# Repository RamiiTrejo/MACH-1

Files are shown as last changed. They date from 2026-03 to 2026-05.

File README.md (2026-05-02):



# Mach-1
Proyecto de robot seguidor de línea de alta velocidad, orientado a competencias de Line Follower Racing (LNR). Está diseñado para la categoría profesional, incorporando soluciones avanzadas como un sistema de succión que mejora la adherencia y el rendimiento en pista.

# Objetivos
Desarrollar un vehículo autónomo capaz de detectar y seguir una trayectoria con alta precisión y velocidad, optimizando tanto el hardware como el software para lograr un desempeño competitivo.

# Componentes
- ATMEGA238P, AU
- TA6586
- MOTOR CORELESS 8520
- TURBINA CON MOTOR CORELESS 716
- REGLETA QTR8A
- BATERÍA 2 350mAh~450mAh

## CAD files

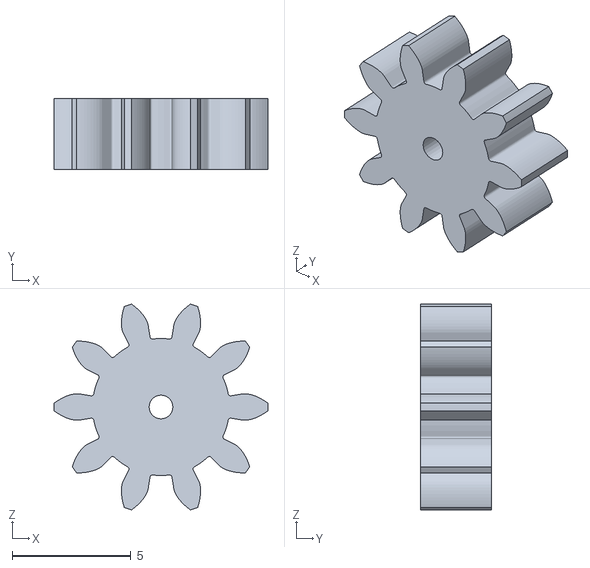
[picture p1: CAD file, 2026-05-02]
3D HARDWARE MACH/PIÑON 10T.stl
9.00 x 3.00 x 8.65

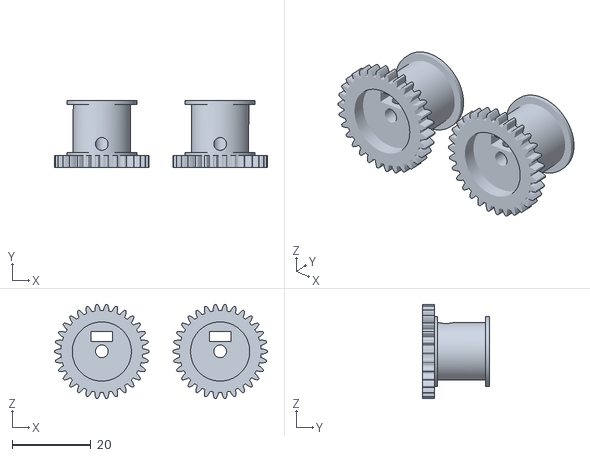
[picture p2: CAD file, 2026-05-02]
3D HARDWARE MACH/RUEDAS 30T.stl
54.0 x 17.0 x 23.9

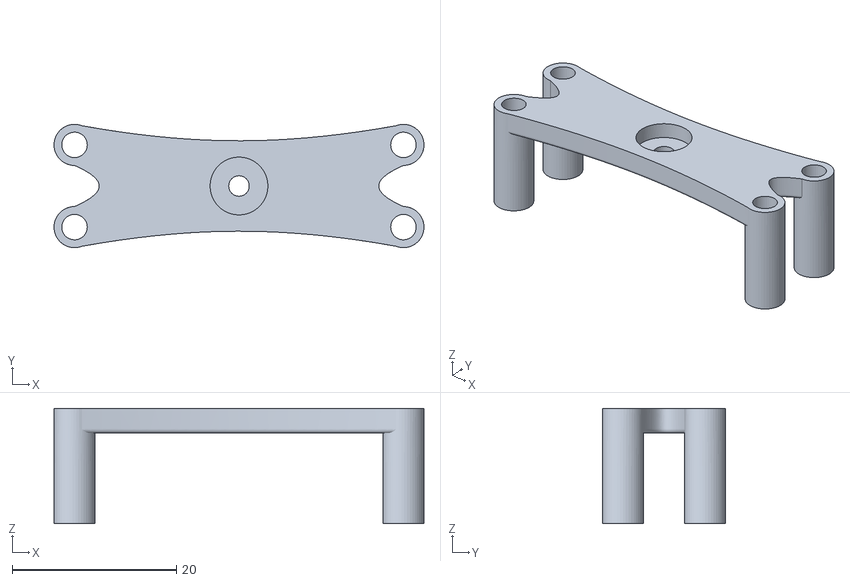
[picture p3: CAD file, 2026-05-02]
3D HARDWARE MACH/SOPORTE TURBINA VELO_.stl
45.0 x 15.0 x 14.0

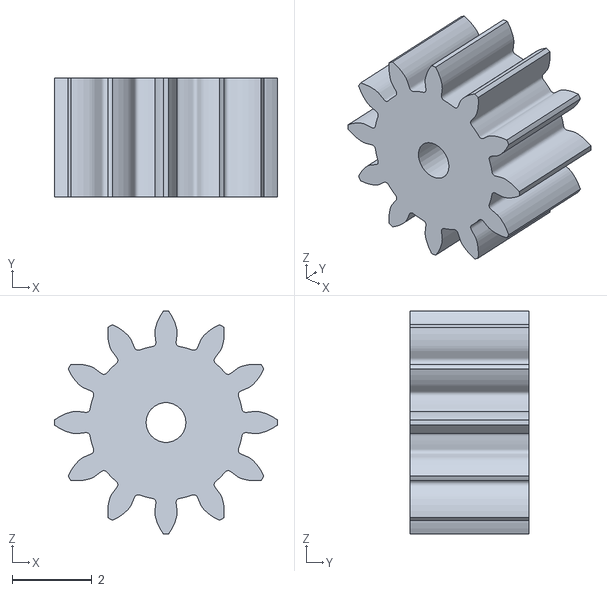
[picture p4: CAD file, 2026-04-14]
3D HARDWARE MACH/Piñón 12T.stl
5.60 x 3.00 x 5.60

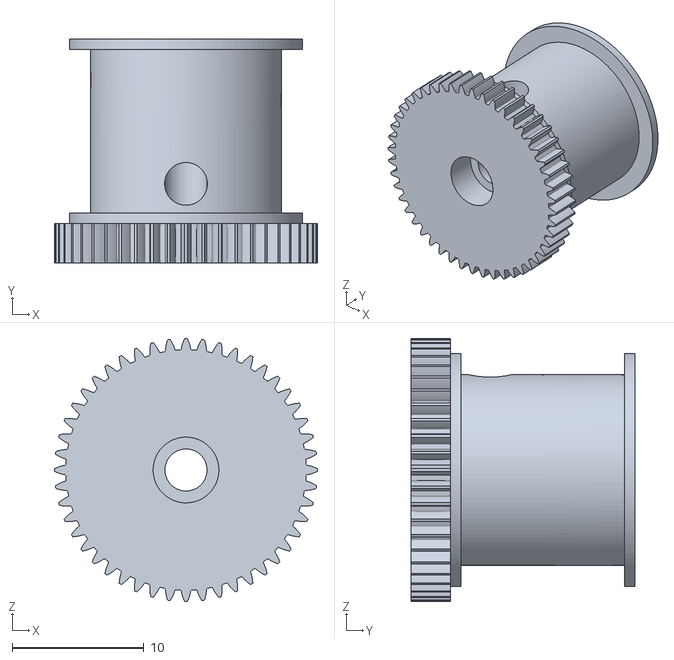
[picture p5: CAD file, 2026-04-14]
3D HARDWARE MACH/Rueda Engranaje 48T.stl
20.0 x 17.0 x 20.0

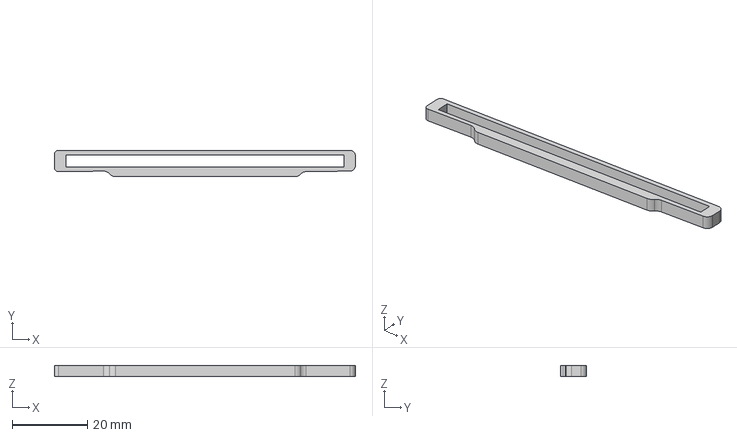
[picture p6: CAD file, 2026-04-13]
3D HARDWARE MACH/Barra separadora.step
80.0 x 7.00 x 3.00 mm

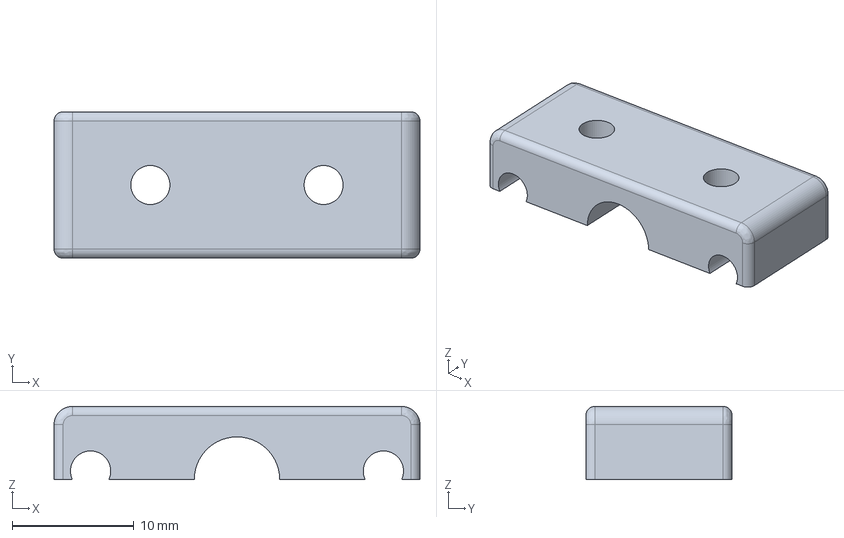
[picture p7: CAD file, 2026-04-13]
3D HARDWARE MACH/BRACKET SUPERIOR.step
30.0 x 12.0 x 6.00 mm

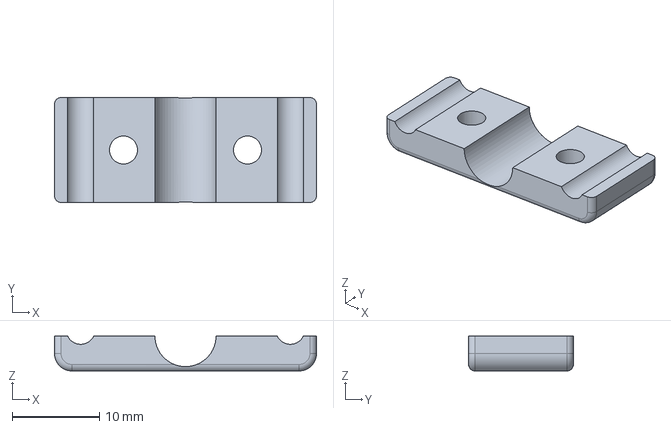
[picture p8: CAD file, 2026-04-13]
3D HARDWARE MACH/BRACKET INFERIOR.step
30.0 x 12.0 x 4.00 mm

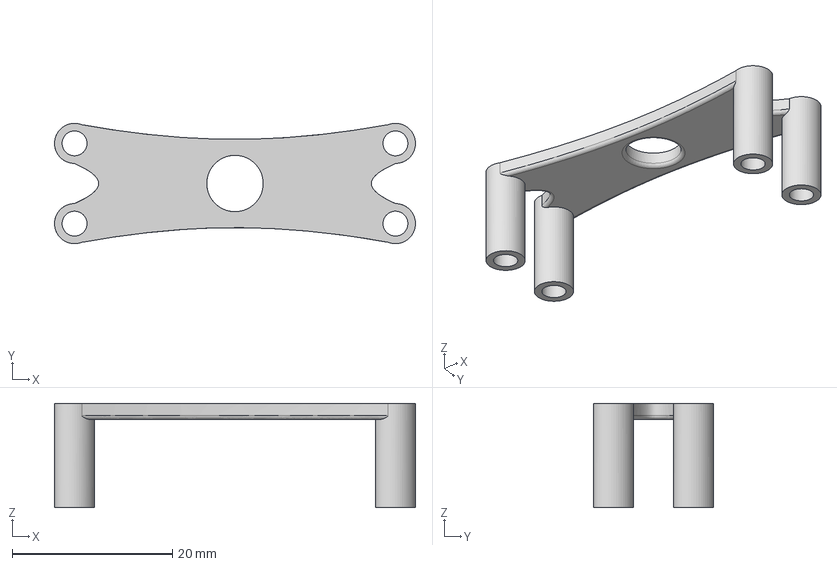
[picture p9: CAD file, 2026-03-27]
3D HARDWARE MACH/TURBINA VELO.step
45.0 x 15.0 x 13.0 mm

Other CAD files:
3D HARDWARE MACH/RUEDA Y ENGRANAJE 48T.step
3D HARDWARE MACH/PIÑON 12T.step
3D HARDWARE MACH/BRACKET INFERIOR.stl
3D HARDWARE MACH/BRACKET SUPERIOR.stl
3D HARDWARE MACH/Barra separadora.stl
3D HARDWARE MACH/TURBINA VELO_.stl

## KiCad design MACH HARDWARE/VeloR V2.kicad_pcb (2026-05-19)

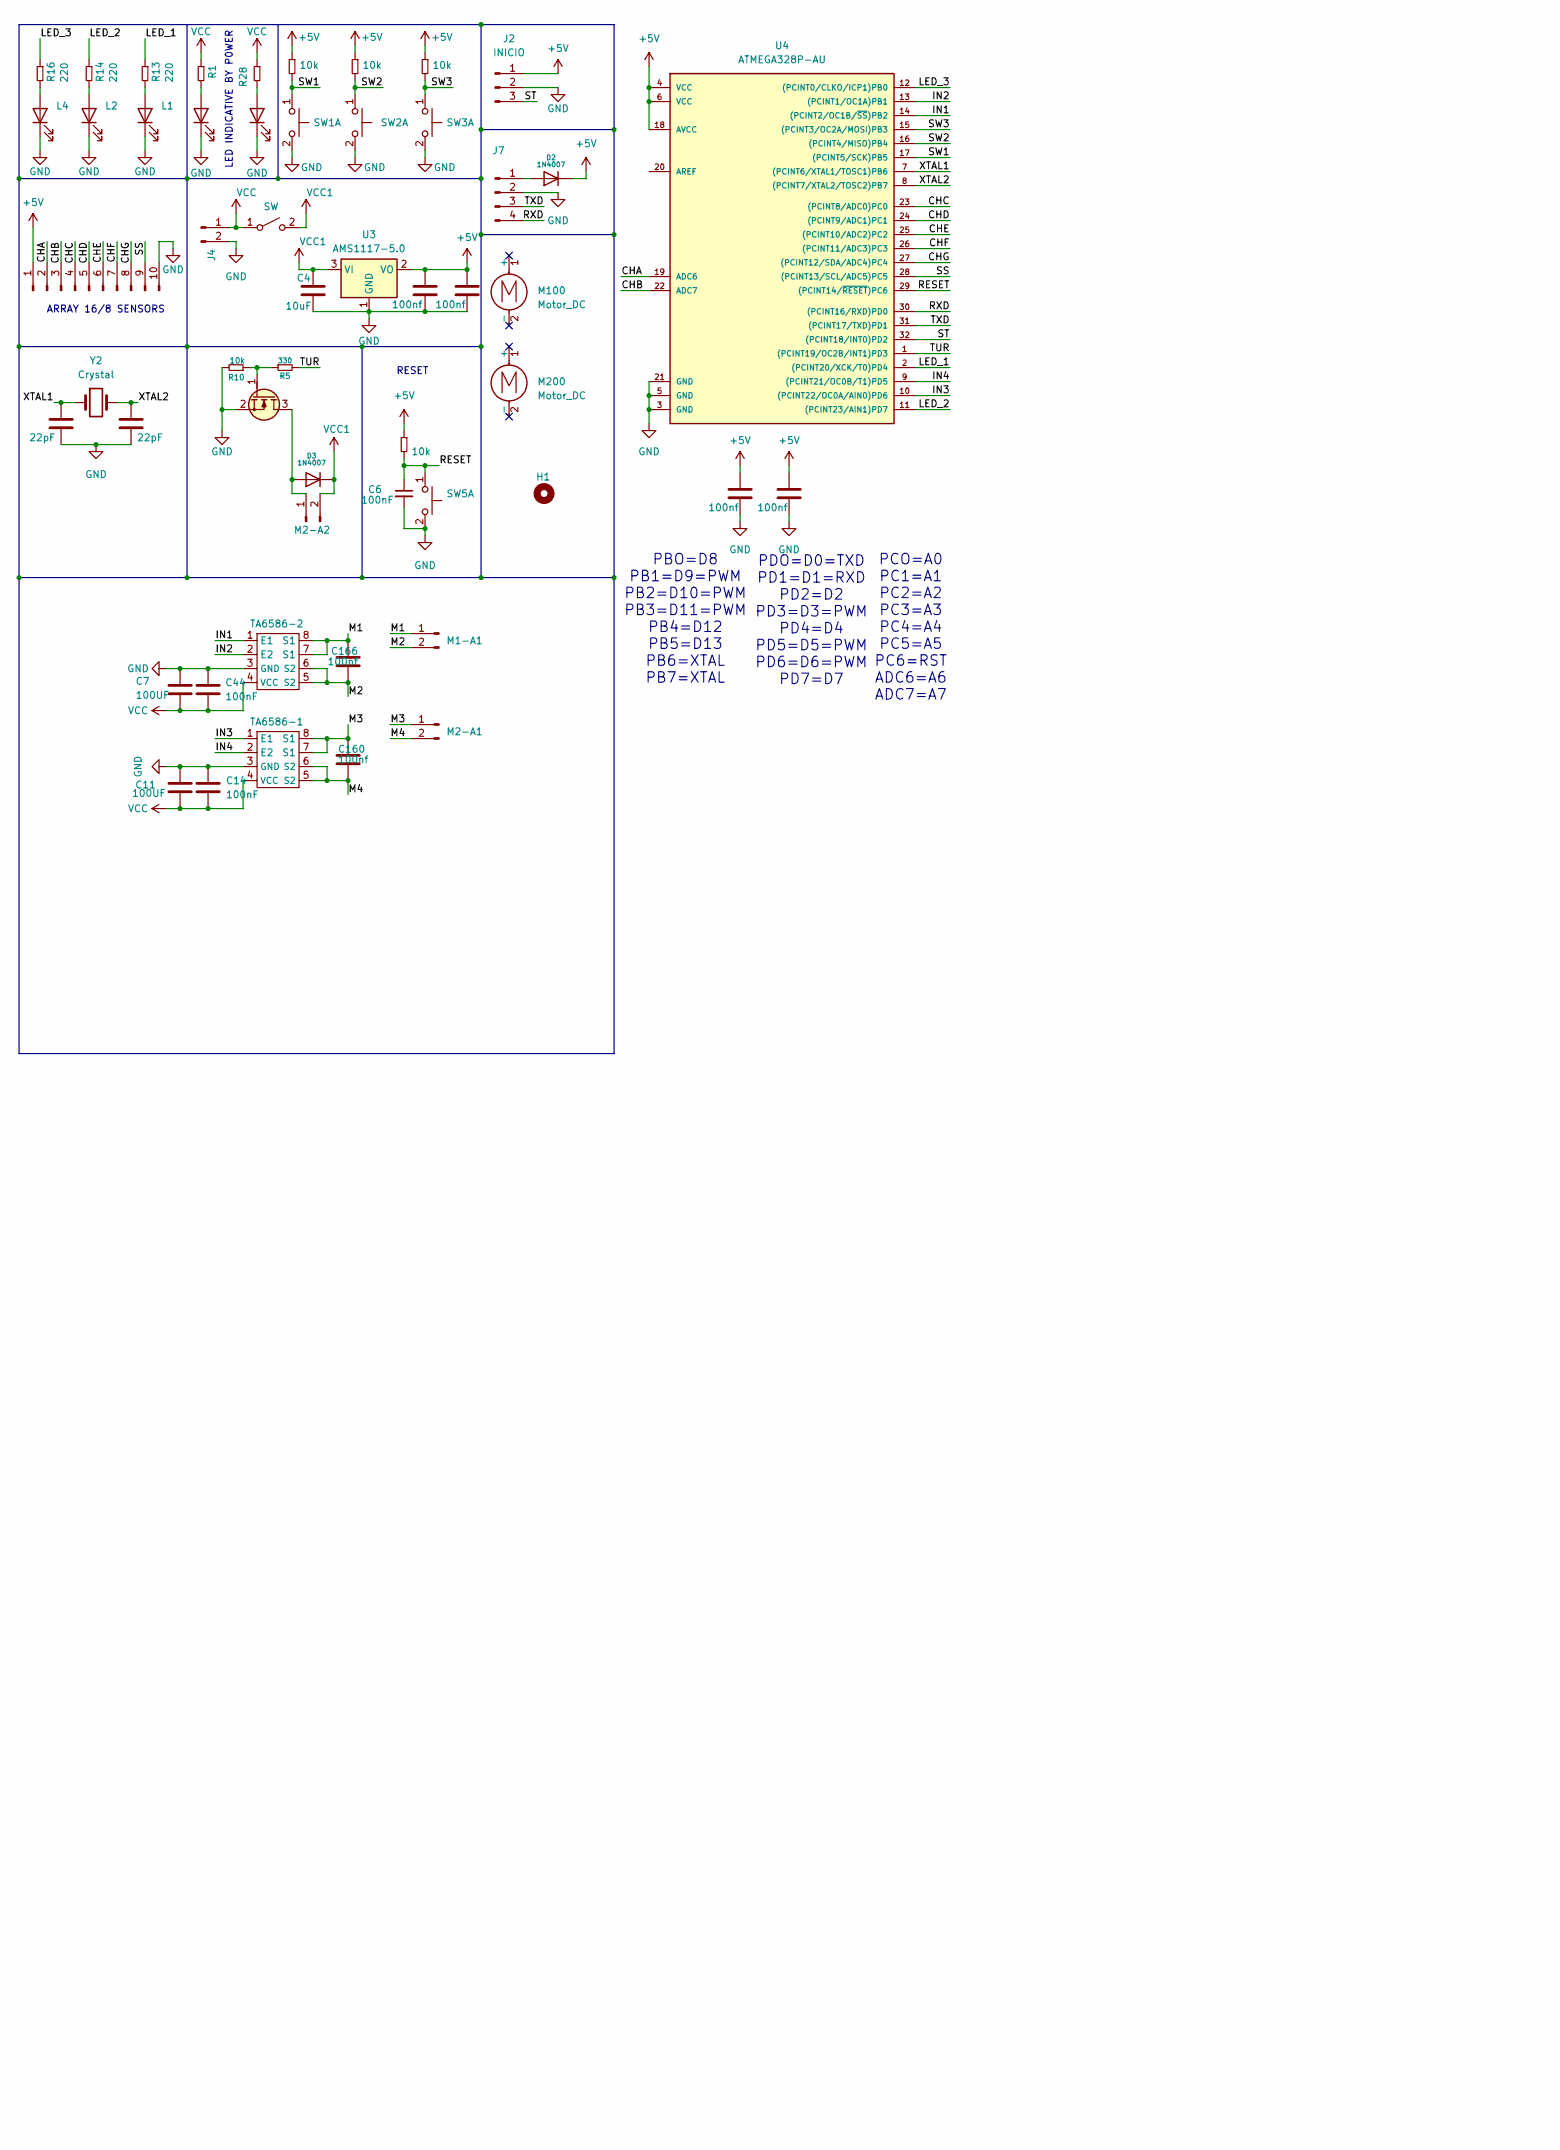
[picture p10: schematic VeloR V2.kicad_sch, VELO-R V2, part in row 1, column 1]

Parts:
C1, C2, C3, C15, C160, C166: 100nf; C_0805_2012Metric_Pad1.18x1.45mm_HandSolder
C4: 10uF; C_1206_3216Metric_Pad1.33x1.80mm_HandSolder
C5, C9: 22pF; C_0805_2012Metric_Pad1.18x1.45mm_HandSolder
C6, C14, C44: 100nF; C_0805_2012Metric_Pad1.18x1.45mm_HandSolder
C7, C11: 100UF; CP_EIA-7343-20_Kemet-V
D1, D11: LED; LED_0805_2012Metric_Pad1.15x1.40mm_HandSolder
D2, D3: 1N4007; D_SMA
H1: MountingHole; TURBINA
J2: INICIO; PinHeader_1x03_P2.54mm_Vertical
J3: Conn_01x10_Pin; JST_XH_S10B-XH-A_1x10_P2.50mm_Horizontal
J4: Conn_01x02_Pin; JST_XH_B3B-XH-A_1x03_P2.50mm_Vertical
J7: Conn_01x04_Pin; PinHeader_1x04_P2.54mm_Horizontal
L1, L2, L4: LED; LED_0805_2012Metric_Pad1.15x1.40mm_HandSolder
M1-A1, M2-A1, M2-A2: Conn_01x02_Pin; Hirose_DF13-02P-1.25DSA_1x02_P1.25mm_Vertical
M100, M200: Motor_DC; Coreless motor
Q1: AO3400A; SOT-23
R1, R28: 1K; R_1206_3216Metric_Pad1.30x1.75mm_HandSolder
R2, R3, R4, R6: 10k; R_1206_3216Metric_Pad1.30x1.75mm_HandSolder
R5: 330; R_0805_2012Metric_Pad1.20x1.40mm_HandSolder
R10: 10k; R_0805_2012Metric_Pad1.20x1.40mm_HandSolder
R13, R14, R16: 220; R_1206_3216Metric_Pad1.30x1.75mm_HandSolder
SW1, SW2, SW3, SW5: SW_Push_Dual_x2; SW SMD 3.5X6X5
SW6: SW; PinHeader_1x03_P2.54mm_Vertical
TA6586-1, TA6586-2: DIP-8_W7.62mm
U3: AMS1117-5.0; SOT-223-3_TabPin2
U4: ATMEGA328P-AU; TQFP-32_7x7mm_P0.8mm
Y2: Crystal; Crystal_HC49-4H_Vertical

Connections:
+5V: C1.1, C2.1, C3.1, C15.1, D2.1 (K), J2.1, J3.1, R2.1, R3.1, R4.1, R6.1, U3.2 (VO), U4.4 (VCC), U4.6 (VCC), U4.18 (AVCC)
/CHA: J3.2, U4.19 (ADC6)
/CHB: J3.3, U4.22 (ADC7)
/CHC: J3.4, U4.23 ((PCINT8/ADC0)PC0)
/CHD: J3.5, U4.24 ((PCINT9/ADC1)PC1)
/CHE: J3.6, U4.25 ((PCINT10/ADC2)PC2)
/CHF: J3.7, U4.26 ((PCINT11/ADC3)PC3)
/CHG: J3.8, U4.27 ((PCINT12/SDA/ADC4)PC4)
/IN1: TA6586-2.1 (E1), U4.14 ((PCINT2/OC1B/~SS)PB2)
/IN2: TA6586-2.2 (E2), U4.13 ((PCINT1/OC1A)PB1)
/IN3: TA6586-1.1 (E1), U4.10 ((PCINT22/OC0A/AIN0)PD6)
/IN4: TA6586-1.2 (E2), U4.9 ((PCINT21/OC0B/T1)PD5)
/LED_1: R13.1, U4.2 ((PCINT20/XCK/T0)PD4)
/LED_2: R14.1, U4.11 ((PCINT23/AIN1)PD7)
/LED_3: R16.1, U4.12 ((PCINT0/CLKO/ICP1)PB0)
/M1: C166.1, M1-A1.1, TA6586-2.7 (S1), TA6586-2.8 (S1)
/M2: C166.2, M1-A1.2, TA6586-2.5 (S2), TA6586-2.6 (S2)
/M3: C160.1, M2-A1.1, TA6586-1.7 (S1), TA6586-1.8 (S1)
/M4: C160.2, M2-A1.2, TA6586-1.5 (S2), TA6586-1.6 (S2)
/RESET: C6.1, R6.2, SW5.1 (C), U4.29 ((PCINT14/~RESET)PC6)
/RXD: J7.4, U4.30 ((PCINT16/RXD)PD0)
/SS: J3.9, U4.28 ((PCINT13/SCL/ADC5)PC5)
/ST: J2.3, U4.32 ((PCINT18/INT0)PD2)
/SW1: R2.2, SW1.1 (C), U4.17 ((PCINT5/SCK)PB5)
/SW2: R3.2, SW2.1 (C), U4.16 ((PCINT4/MISO)PB4)
/SW3: R4.2, SW3.1 (C), U4.15 ((PCINT3/OC2A/MOSI)PB3)
/TUR: R5.2, U4.1 ((PCINT19/OC2B/INT1)PD3)
/TXD: J7.3, U4.31 ((PCINT17/TXD)PD1)
/XTAL1: C5.1, U4.7 ((PCINT6/XTAL1/TOSC1)PB6), Y2.1
/XTAL2: C9.1, U4.8 ((PCINT7/XTAL2/TOSC2)PB7), Y2.2
GND: C1.2, C2.2, C3.2, C4.2, C5.2, C6.2, C7.1, C9.2, C11.1, C14.1, C15.2, C44.1, D1.1 (K), D11.1 (K), J2.2, J3.10, J4.2, J7.2, L1.1 (K), L2.1 (K), L4.1 (K), Q1.2 (S), R10.2, SW1.2 (D), SW2.2 (D), SW3.2 (D), SW5.2 (D), TA6586-1.3 (GND), TA6586-2.3 (GND), U3.1 (GND), U4.3 (GND), U4.5 (GND), U4.21 (GND)
unnamed: D1.2 (A), R1.2
unnamed: D2.2 (A), J7.1
unnamed: D3.2 (A), M2-A2.1, Q1.3 (D)
unnamed: D11.2 (A), R28.2
unnamed: L1.2 (A), R13.2
unnamed: L2.2 (A), R14.2
unnamed: L4.2 (A), R16.2
unnamed: Q1.1 (G), R5.1, R10.1
VCC: C7.2, C11.2, C14.2, C44.2, J4.1, R1.1, R28.1, SW6.1 (A), TA6586-1.4 (VCC), TA6586-2.4 (VCC)
VCC1: C4.1, D3.1 (K), M2-A2.2, SW6.2 (B), U3.3 (VI)

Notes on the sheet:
PCO=A0 PC1=A1 PC2=A2 PC3=A3 PC4=A4 PC5=A5 PC6=RST ADC6=A6 ADC7=A7
LED INDICATIVE BY P0WER
PBO=D8 PB1=D9=PWM PB2=D10=PWM PB3=D11=PWM PB4=D12 PB5=D13 PB6=XTAL PB7=XTAL
ARRAY 16/8 SENSORS
RESET
PDO=D0=TXD PD1=D1=RXD PD2=D2 PD3=D3=PWM PD4=D4 PD5=D5=PWM PD6=D6=PWM PD7=D7

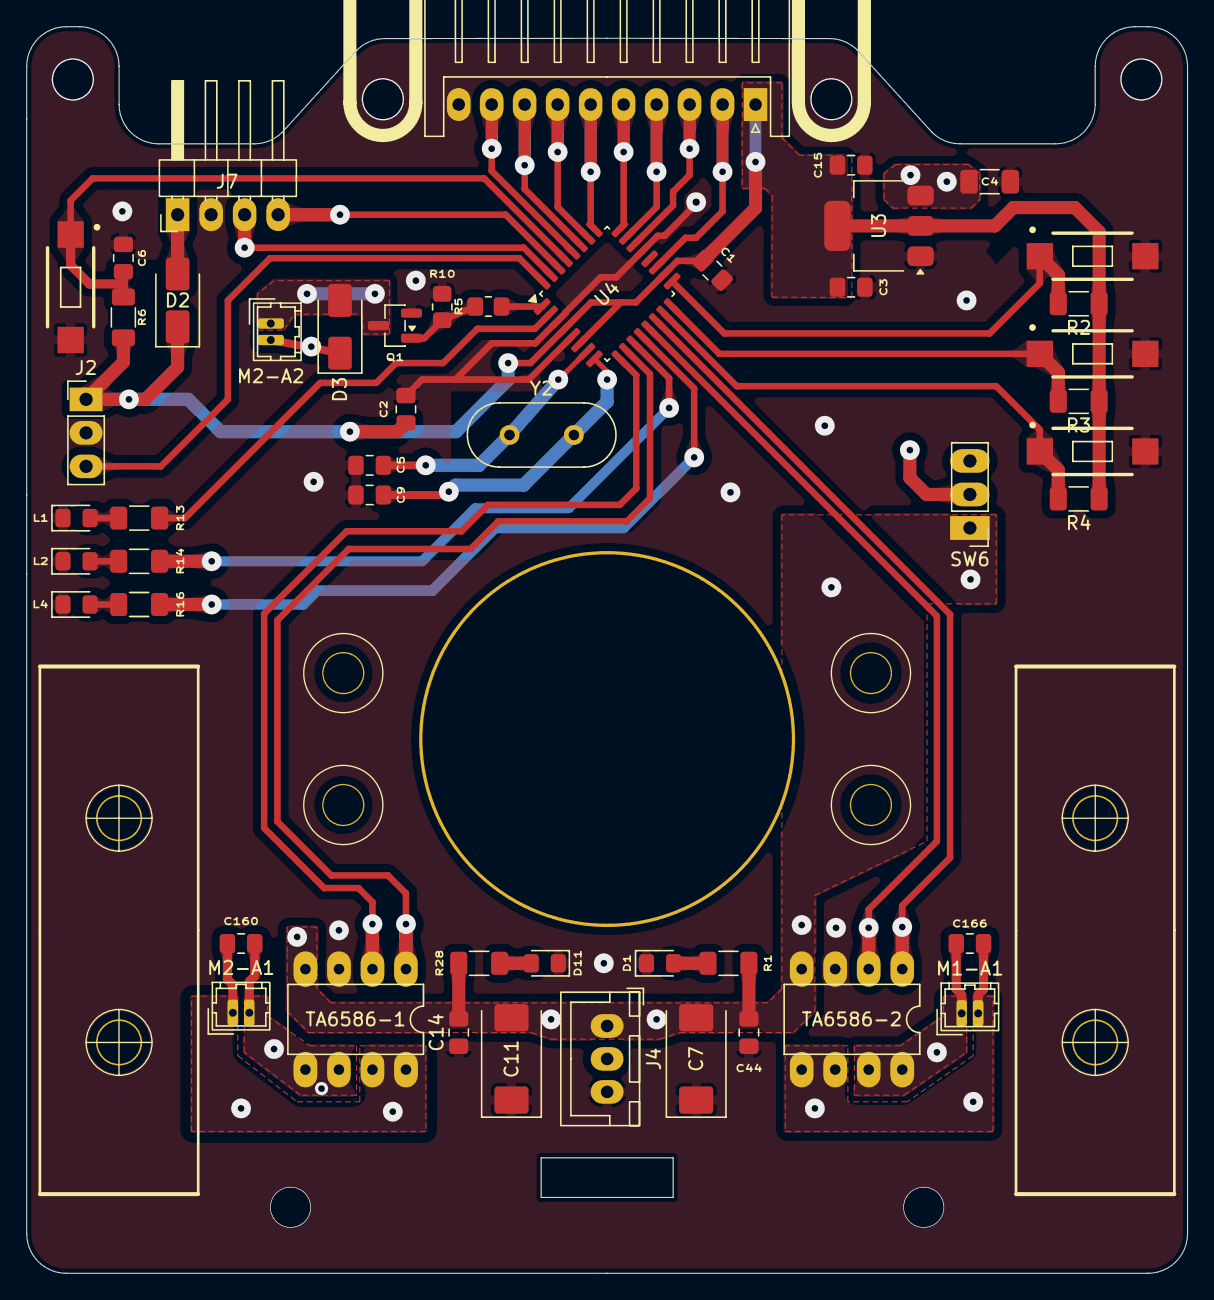
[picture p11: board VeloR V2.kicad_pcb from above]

Board: 2 copper layers, 88.0 x 94.5 mm, 53 parts (0 on the bottom side), 41 nets.

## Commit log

2026-05-02 Add files via upload
    MACH, TRUBINE, DRIVERS TA6586, CNC MACHINE
    [VeloR V2.kicad_pcb, VeloR V2.kicad_sch]
2026-05-02 Add battery specifications to README
